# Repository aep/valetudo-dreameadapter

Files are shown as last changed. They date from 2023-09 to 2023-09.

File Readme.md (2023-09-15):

# Dreame Breakout

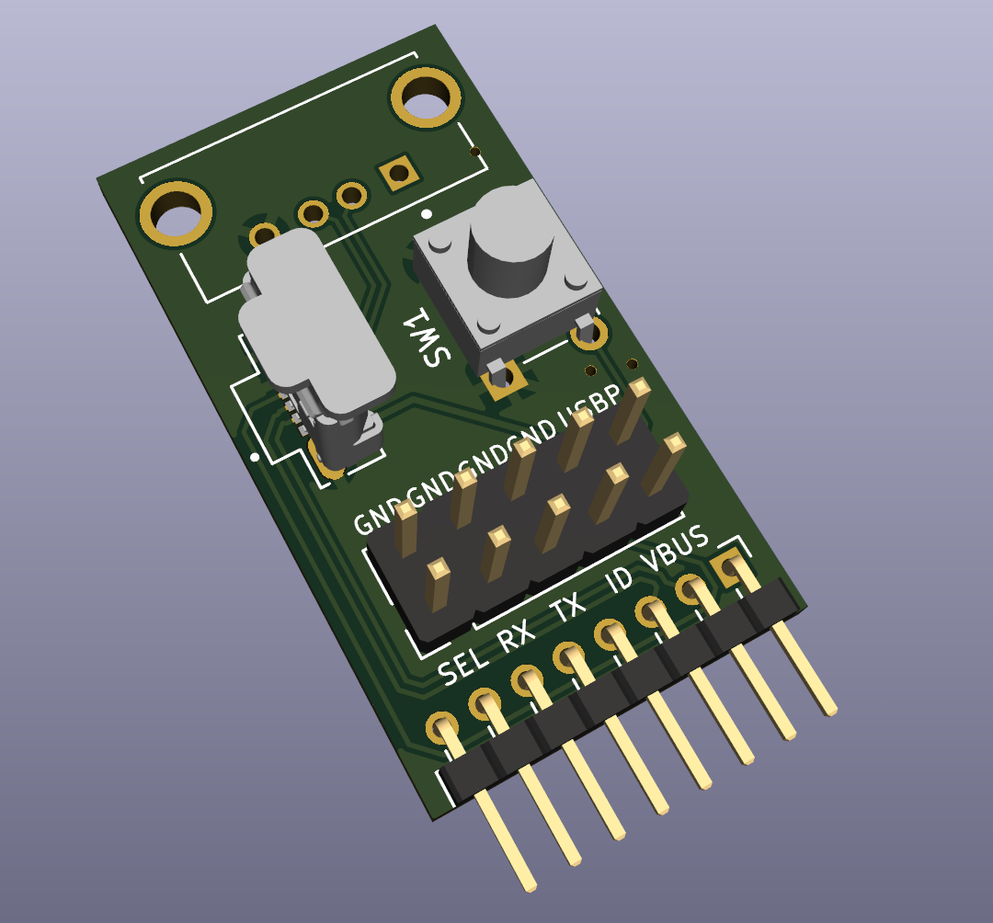
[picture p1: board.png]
[](./board.png)

This is a cheaper version of the original [valetudo-dreameadapter](https://github.com/Hypfer/valetudo-dreameadapter)
for rooting dreame robots.

It is optimized for manufacturing and can be completely assembled by JLC using the files in "production".
For that reason, it is less useful for developers and really only the minimum needed for user to root a bot.

I'll update this readme once someone tested it to actually work.

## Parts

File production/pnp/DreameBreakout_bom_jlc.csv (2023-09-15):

Comment | Designator | Footprint | LCSC Part # | LCSC Part #
105133-0011 | J2 | MOLEX_105133-0011 |  | C586226
Conn_02x05_Odd_Even | J6 | PinHeader_2x05_P2.54mm_Vertical |  | C6332208
OTG_USB | J5 | ONSHORE_USB-A1VSB6 |  | C708904
To Robot SoC | J1.1 | PinHeader_1x08_P2.00mm_Horizontal |  | C2938468
SoC_Boot_SEL_BTN | SW1 | SW_TH_Tactile_Omron_B3F-10xx |  | C93153

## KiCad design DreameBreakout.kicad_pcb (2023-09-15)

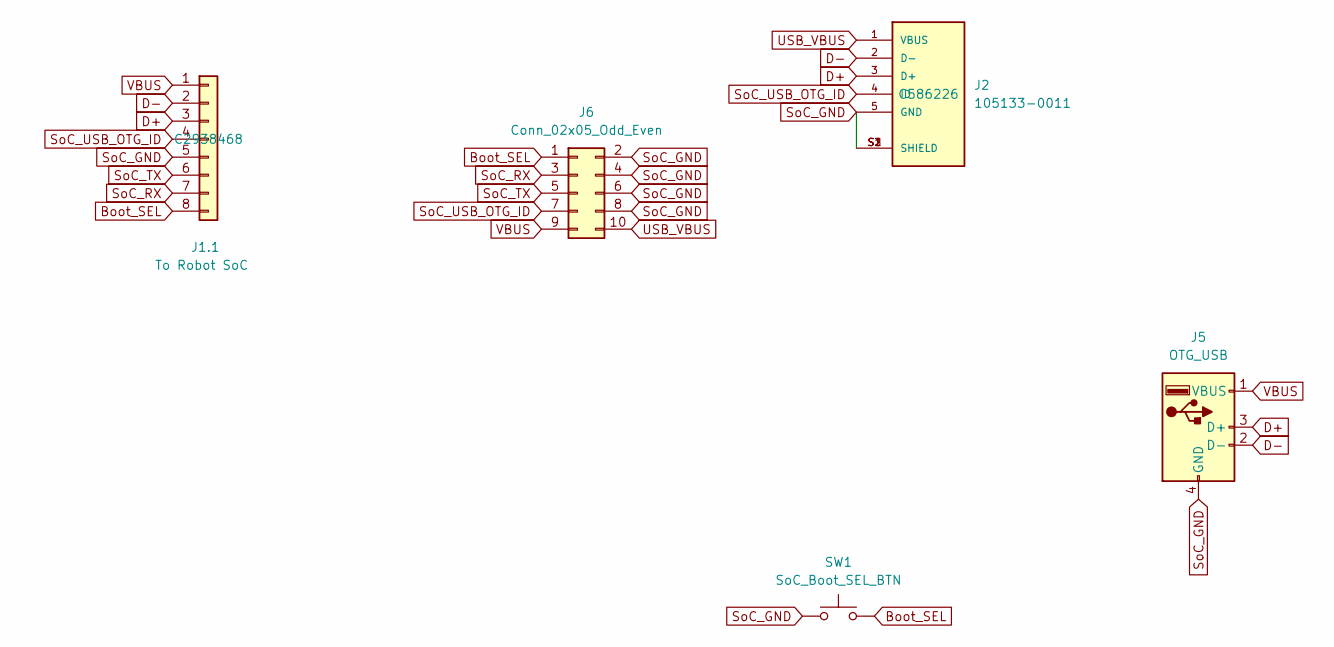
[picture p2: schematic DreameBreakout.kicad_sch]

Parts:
J1.1: To Robot SoC; PinHeader_1x08_P2.00mm_Horizontal; JLC# C2938468
J2: 105133-0011; MOLEX_105133-0011; PARTREV C; JLC# C586226
J5: OTG_USB; ONSHORE_USB-A1VSB6; JLC# C708904
J6: Conn_02x05_Odd_Even; PinHeader_2x05_P2.54mm_Vertical; JLC# C6332208
SW1: SoC_Boot_SEL_BTN; SW_TH_Tactile_Omron_B3F-10xx; JLC# C93153

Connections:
Boot_SEL: J1.1.8, J6.1, SW1.2
D+: J1.1.3, J2.3 (D+), J5.3 (D+)
D-: J1.1.2, J2.2 (D-), J5.2 (D-)
SoC_GND: J1.1.5, J2.5 (GND), J2.S1 (SHIELD), J2.S2 (SHIELD), J2.S3 (SHIELD), J5.4 (GND), J6.2, J6.4, J6.6, J6.8, SW1.1
SoC_RX: J1.1.7, J6.3
SoC_TX: J1.1.6, J6.5
SoC_USB_OTG_ID: J1.1.4, J2.4 (ID), J6.7
USB_VBUS: J2.1 (VBUS), J6.10
VBUS: J1.1.1, J5.1 (VBUS), J6.9

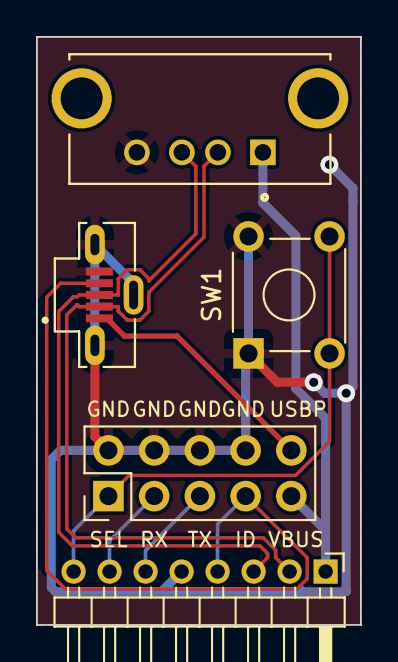
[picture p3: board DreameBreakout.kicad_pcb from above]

Board: 2 copper layers, 18.0 x 32.7 mm, 5 parts (0 on the bottom side), 9 nets.
